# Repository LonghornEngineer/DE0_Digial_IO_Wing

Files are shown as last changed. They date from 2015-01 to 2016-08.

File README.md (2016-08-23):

LHE_BANNER
***
###DE0_Digial_IO_Wing
***
**Digital I/O Expansion Wing for the DE0 FPGA Development Board.**

This is for the [Altera DE0 Development Board by terasIC](http://www.terasic.com.tw/cgi-bin/page/archive.pl?Language=English&No=364). 

See [here for more information](http://longhornengineer.com/category/projects/hardware/de0-digital-io-wing-expansion/).

***
**License Information**

This project is under the [Creative Commons Attribution-ShareAlike 4.0 International License](LICENSE.md). These files are provided with no warranty and should be used at your own risk. 

***

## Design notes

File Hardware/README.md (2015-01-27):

###DE0_Digial_IO_Wing
***
**Digital I/O Expansion Wing for the DE0 FPGA Development Board.**

This is for the [Altera DE0 Development Board by terasIC](http://www.terasic.com.tw/cgi-bin/page/archive.pl?Language=English&No=364). 

Files are for Eagle V6.0+ 

***
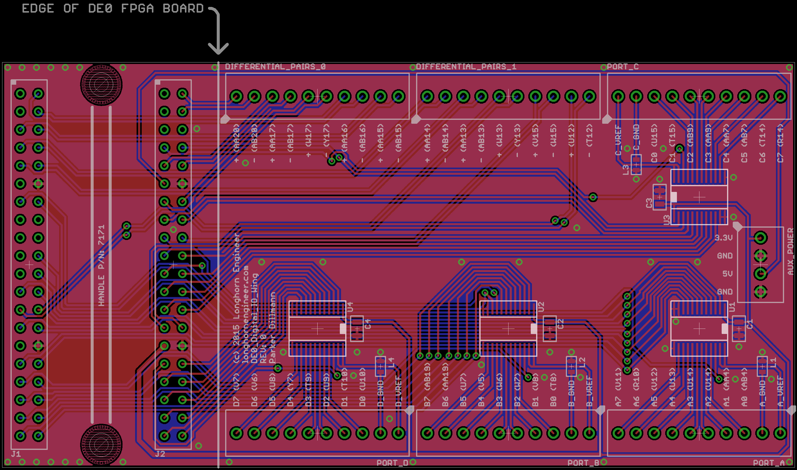
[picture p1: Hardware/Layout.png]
Layout Image


***
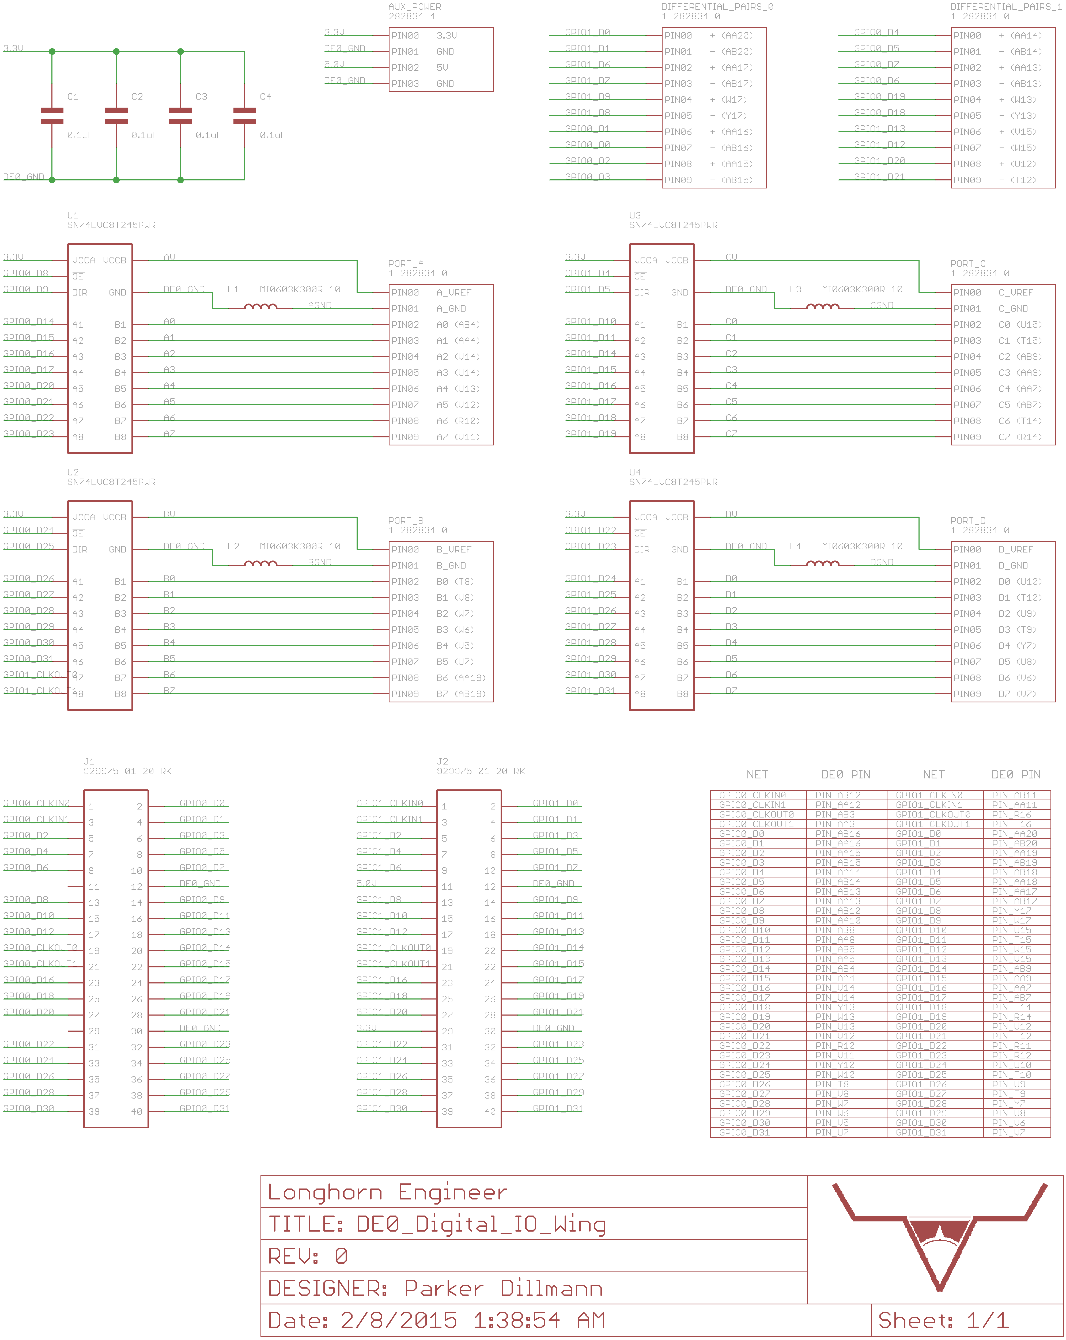
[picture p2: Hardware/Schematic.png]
Schematic Image


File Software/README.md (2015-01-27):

###DE0_Digial_IO_Wing
***
**Digital I/O Expansion Wing for the DE0 FPGA Development Board.**

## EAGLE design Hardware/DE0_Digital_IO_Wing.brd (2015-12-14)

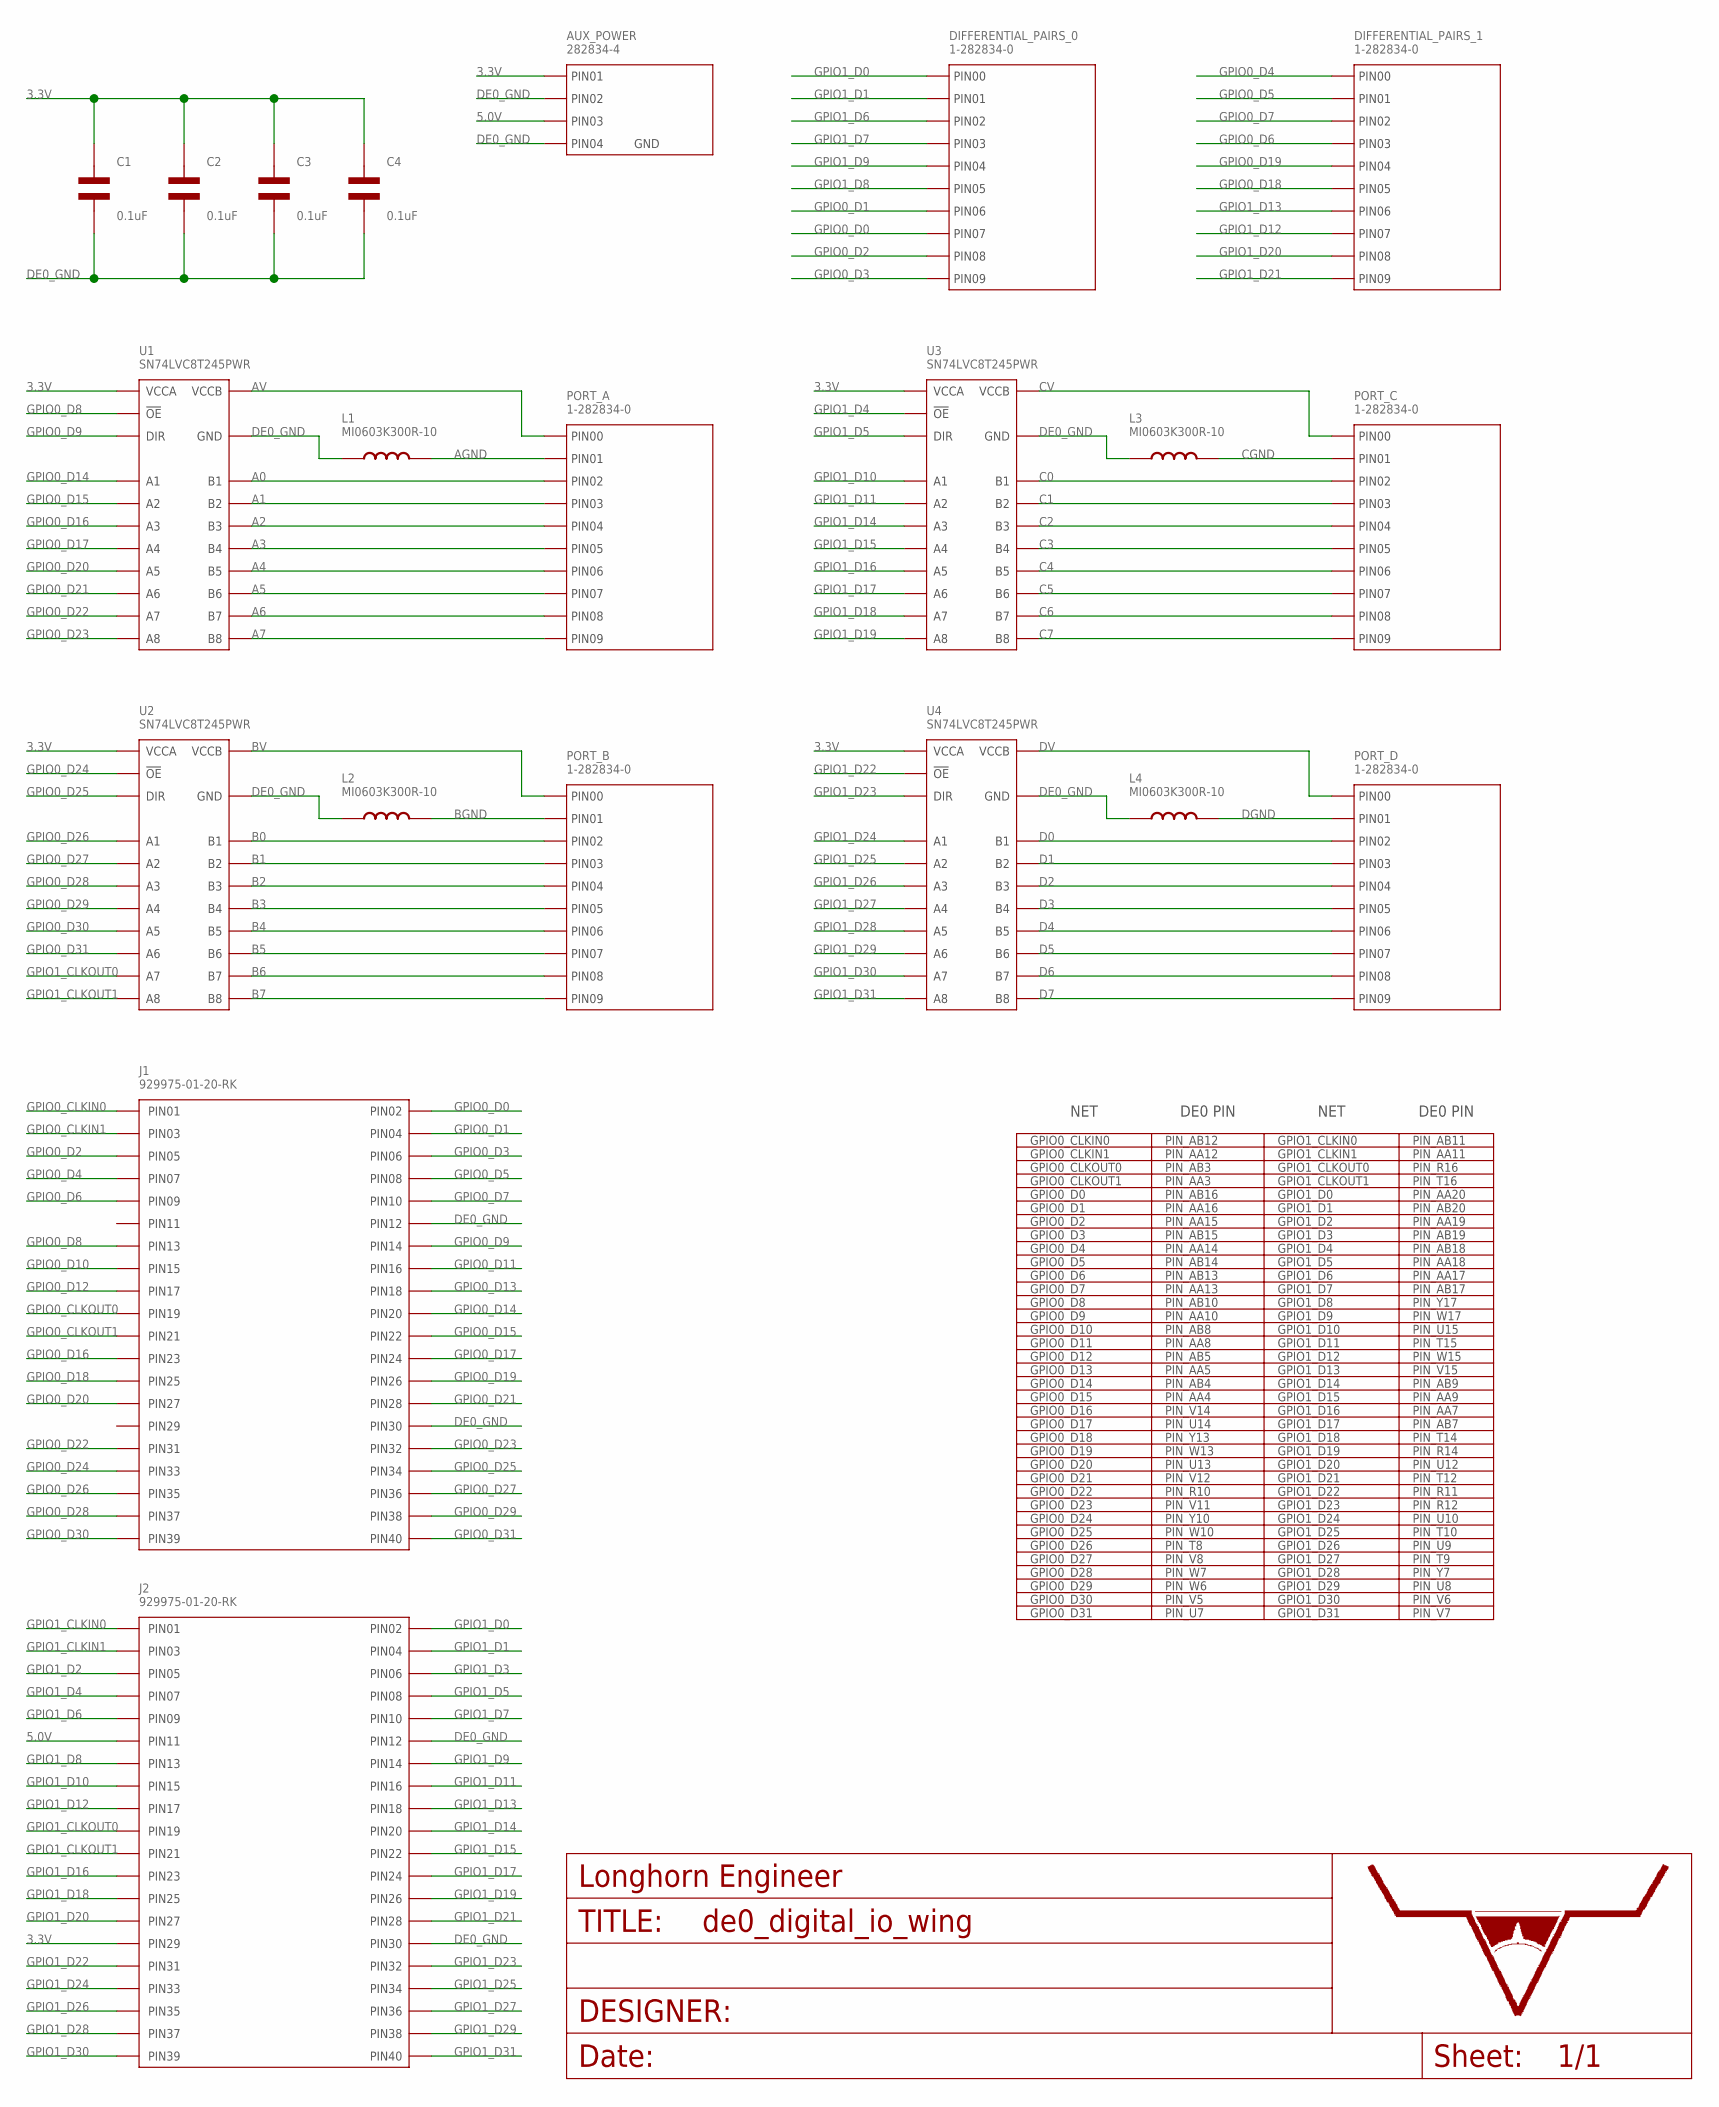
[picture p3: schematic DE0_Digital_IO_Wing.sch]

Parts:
AUX_POWER: 282834-4
C1, C2, C3, C4: 0.1uF; C0805
DIFFERENTIAL_PAIRS_0, DIFFERENTIAL_PAIRS_1: 1-282834-0
FRAME: LHE_FRAME
J1, J2: 929975-01-20-RK; 2.54MM_02X20_PIN_HEADER
L1, L2, L3, L4: MI0603K300R-10; L0603
PORT_A: 1-282834-0
PORT_B: 1-282834-0
PORT_C: 1-282834-0
PORT_D: 1-282834-0
U1, U2, U3, U4: SN74LVC8T245PWR; SN74LVC8T245_TTSOP-24

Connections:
3.3V: AUX_POWER.P$1 (1), C1.P$1, C2.P$1, C3.P$1, C4.P$1, J2.29, U1.P$1 (VCCA), U2.P$1 (VCCA), U3.P$1 (VCCA), U4.P$1 (VCCA)
5.0V: AUX_POWER.P$3 (3), J2.11
A0: PORT_A.P$3 (3), U1.P$21 (B1)
A1: PORT_A.P$4 (4), U1.P$20 (B2)
A2: PORT_A.P$5 (5), U1.P$19 (B3)
A3: PORT_A.P$6 (6), U1.P$18 (B4)
A4: PORT_A.P$7 (7), U1.P$17 (B5)
A5: PORT_A.P$8 (8), U1.P$16 (B6)
A6: PORT_A.P$9 (9), U1.P$15 (B7)
A7: PORT_A.P$10 (10), U1.P$14 (B8)
AGND: L1.P$2, PORT_A.P$2 (2)
AV: PORT_A.P$1 (1), U1.P$23 (VCCB), U1.P$24 (VCCB)
B0: PORT_B.P$3 (3), U2.P$21 (B1)
B1: PORT_B.P$4 (4), U2.P$20 (B2)
B2: PORT_B.P$5 (5), U2.P$19 (B3)
B3: PORT_B.P$6 (6), U2.P$18 (B4)
B4: PORT_B.P$7 (7), U2.P$17 (B5)
B5: PORT_B.P$8 (8), U2.P$16 (B6)
B6: PORT_B.P$9 (9), U2.P$15 (B7)
B7: PORT_B.P$10 (10), U2.P$14 (B8)
BGND: L2.P$2, PORT_B.P$2 (2)
BV: PORT_B.P$1 (1), U2.P$23 (VCCB), U2.P$24 (VCCB)
C0: PORT_C.P$3 (3), U3.P$21 (B1)
C1: PORT_C.P$4 (4), U3.P$20 (B2)
C2: PORT_C.P$5 (5), U3.P$19 (B3)
C3: PORT_C.P$6 (6), U3.P$18 (B4)
C4: PORT_C.P$7 (7), U3.P$17 (B5)
C5: PORT_C.P$8 (8), U3.P$16 (B6)
C6: PORT_C.P$9 (9), U3.P$15 (B7)
C7: PORT_C.P$10 (10), U3.P$14 (B8)
CGND: L3.P$2, PORT_C.P$2 (2)
CV: PORT_C.P$1 (1), U3.P$23 (VCCB), U3.P$24 (VCCB)
D0: PORT_D.P$3 (3), U4.P$21 (B1)
D1: PORT_D.P$4 (4), U4.P$20 (B2)
D2: PORT_D.P$5 (5), U4.P$19 (B3)
D3: PORT_D.P$6 (6), U4.P$18 (B4)
D4: PORT_D.P$7 (7), U4.P$17 (B5)
D5: PORT_D.P$8 (8), U4.P$16 (B6)
D6: PORT_D.P$9 (9), U4.P$15 (B7)
D7: PORT_D.P$10 (10), U4.P$14 (B8)
DE0_GND: AUX_POWER.P$2 (2), AUX_POWER.P$4 (4), C1.P$2, C2.P$2, C3.P$2, C4.P$2, J1.12, J1.30, J2.12, J2.30, L1.P$1, L2.P$1, L3.P$1, L4.P$1, U1.P$11 (GND), U1.P$12 (GND), U1.P$13 (GND), U2.P$11 (GND), U2.P$12 (GND), U2.P$13 (GND), U3.P$11 (GND), U3.P$12 (GND), U3.P$13 (GND), U4.P$11 (GND), U4.P$12 (GND), U4.P$13 (GND)
DGND: L4.P$2, PORT_D.P$2 (2)
DV: PORT_D.P$1 (1), U4.P$23 (VCCB), U4.P$24 (VCCB)
GPIO0_CLKIN0: J1.1
GPIO0_CLKIN1: J1.3
GPIO0_CLKOUT0: J1.19
GPIO0_CLKOUT1: J1.21
GPIO0_D0: DIFFERENTIAL_PAIRS_0.P$8 (8), J1.2
GPIO0_D1: DIFFERENTIAL_PAIRS_0.P$7 (7), J1.4
GPIO0_D2: DIFFERENTIAL_PAIRS_0.P$9 (9), J1.5
GPIO0_D3: DIFFERENTIAL_PAIRS_0.P$10 (10), J1.6
GPIO0_D4: DIFFERENTIAL_PAIRS_1.P$1 (1), J1.7
GPIO0_D5: DIFFERENTIAL_PAIRS_1.P$2 (2), J1.8
GPIO0_D6: DIFFERENTIAL_PAIRS_1.P$4 (4), J1.9
GPIO0_D7: DIFFERENTIAL_PAIRS_1.P$3 (3), J1.10
GPIO0_D8: J1.13, U1.P$22 (!OE)
GPIO0_D9: J1.14, U1.P$2 (DIR)
GPIO0_D10: J1.15
GPIO0_D11: J1.16
GPIO0_D12: J1.17
GPIO0_D13: J1.18
GPIO0_D14: J1.20, U1.P$3 (A1)
GPIO0_D15: J1.22, U1.P$4 (A2)
GPIO0_D16: J1.23, U1.P$5 (A3)
GPIO0_D17: J1.24, U1.P$6 (A4)
GPIO0_D18: DIFFERENTIAL_PAIRS_1.P$6 (6), J1.25
GPIO0_D19: DIFFERENTIAL_PAIRS_1.P$5 (5), J1.26
GPIO0_D20: J1.27, U1.P$7 (A5)
GPIO0_D21: J1.28, U1.P$8 (A6)
GPIO0_D22: J1.31, U1.P$9 (A7)
GPIO0_D23: J1.32, U1.P$10 (A8)
GPIO0_D24: J1.33, U2.P$22 (!OE)
GPIO0_D25: J1.34, U2.P$2 (DIR)
GPIO0_D26: J1.35, U2.P$3 (A1)
GPIO0_D27: J1.36, U2.P$4 (A2)
GPIO0_D28: J1.37, U2.P$5 (A3)
GPIO0_D29: J1.38, U2.P$6 (A4)
GPIO0_D30: J1.39, U2.P$7 (A5)
GPIO0_D31: J1.40, U2.P$8 (A6)
GPIO1_CLKIN0: J2.1
GPIO1_CLKIN1: J2.3
GPIO1_CLKOUT0: J2.19, U2.P$9 (A7)
GPIO1_CLKOUT1: J2.21, U2.P$10 (A8)
GPIO1_D0: DIFFERENTIAL_PAIRS_0.P$1 (1), J2.2
GPIO1_D1: DIFFERENTIAL_PAIRS_0.P$2 (2), J2.4
GPIO1_D2: J2.5
GPIO1_D3: J2.6
GPIO1_D4: J2.7, U3.P$22 (!OE)
GPIO1_D5: J2.8, U3.P$2 (DIR)
GPIO1_D6: DIFFERENTIAL_PAIRS_0.P$3 (3), J2.9
GPIO1_D7: DIFFERENTIAL_PAIRS_0.P$4 (4), J2.10
GPIO1_D8: DIFFERENTIAL_PAIRS_0.P$6 (6), J2.13
GPIO1_D9: DIFFERENTIAL_PAIRS_0.P$5 (5), J2.14
GPIO1_D10: J2.15, U3.P$3 (A1)
GPIO1_D11: J2.16, U3.P$4 (A2)
GPIO1_D12: DIFFERENTIAL_PAIRS_1.P$8 (8), J2.17
GPIO1_D13: DIFFERENTIAL_PAIRS_1.P$7 (7), J2.18
GPIO1_D14: J2.20, U3.P$5 (A3)
GPIO1_D15: J2.22, U3.P$6 (A4)
GPIO1_D16: J2.23, U3.P$7 (A5)
GPIO1_D17: J2.24, U3.P$8 (A6)
GPIO1_D18: J2.25, U3.P$9 (A7)
GPIO1_D19: J2.26, U3.P$10 (A8)
GPIO1_D20: DIFFERENTIAL_PAIRS_1.P$9 (9), J2.27
GPIO1_D21: DIFFERENTIAL_PAIRS_1.P$10 (10), J2.28
GPIO1_D22: J2.31, U4.P$22 (!OE)
GPIO1_D23: J2.32, U4.P$2 (DIR)
GPIO1_D24: J2.33, U4.P$3 (A1)
GPIO1_D25: J2.34, U4.P$4 (A2)
GPIO1_D26: J2.35, U4.P$5 (A3)
GPIO1_D27: J2.36, U4.P$6 (A4)
GPIO1_D28: J2.37, U4.P$7 (A5)
GPIO1_D29: J2.38, U4.P$8 (A6)
GPIO1_D30: J2.39, U4.P$9 (A7)
GPIO1_D31: J2.40, U4.P$10 (A8)

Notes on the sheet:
GPIO0_CLKIN0 GPIO0_CLKIN1 GPIO0_CLKOUT0 GPIO0_CLKOUT1 GPIO0_D0 GPIO0_D1 GPIO0_D2 GPIO0_D3 GPIO0_D4 GPIO0_D5 GPIO0_D6 GPIO0_D7 GPIO0_D8 GPIO0_D9 GPIO0_D10 GPIO0_D11 GPIO0_D12 GPIO0_D13 GPIO0_D14 GPIO0_D15 GPIO0_D16 GPIO0_D17 GPIO0_D18 GPIO0_D19 GPIO0_D20 GPIO0_D21 GPIO0_D22 GPIO0_D23 GPIO0_D24 GPIO0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
GPIO1_CLKIN0 GPIO1_CLKIN1 GPIO1_CLKOUT0 GPIO1_CLKOUT1 GPIO1_D0 GPIO1_D1 GPIO1_D2 GPIO1_D3 GPIO1_D4 GPIO1_D5 GPIO1_D6 GPIO1_D7 GPIO1_D8 GPIO1_D9 GPIO1_D10 GPIO1_D11 GPIO1_D12 GPIO1_D13 GPIO1_D14 GPIO1_D15 GPIO1_D16 GPIO1_D17 GPIO1_D18 GPIO1_D19 GPIO1_D20 GPIO1_D21 GPIO1_D22 GPIO1_D23 GPIO1_D24 GPIO1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
PIN_AB12 PIN_AA12 PIN_AB3 PIN_AA3 PIN_AB16 PIN_AA16 PIN_AA15 PIN_AB15 PIN_AA14 PIN_AB14 PIN_AB13 PIN_AA13 PIN_AB10 PIN_AA10 PIN_AB8 PIN_AA8 PIN_AB5 PIN_AA5 PIN_AB4 PIN_AA4 PIN_V14 PIN_U14 PIN_Y13 PIN_W13 PIN_U13 PIN_V12 PIN_R10 PIN_V11 PIN_Y10 PIN_W10 PIN_T8 PIN_V8 PIN_W7 PIN_W6 PIN_V5 PIN_U7
PIN_AB11 PIN_AA11 PIN_R16 PIN_T16 PIN_AA20 PIN_AB20 PIN_AA19 PIN_AB19 PIN_AB18 PIN_AA18 PIN_AA17 PIN_AB17 PIN_Y17 PIN_W17 PIN_U15 PIN_T15 PIN_W15 PIN_V15 PIN_AB9 PIN_AA9 PIN_AA7 PIN_AB7 PIN_T14 PIN_R14 PIN_U12 PIN_T12 PIN_R11 PIN_R12 PIN_U10 PIN_T10 PIN_U9 PIN_T9 PIN_Y7 PIN_U8 PIN_V6 PIN_V7
NET
DE0 PIN

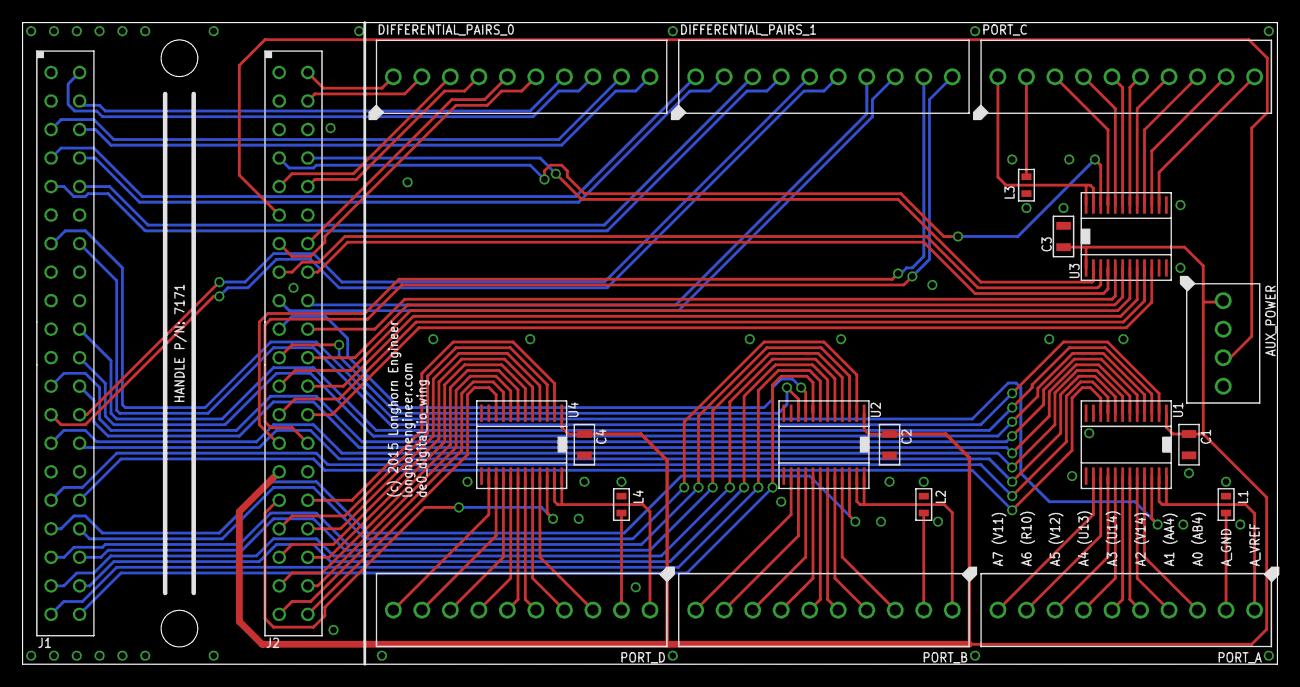
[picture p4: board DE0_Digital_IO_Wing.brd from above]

Board: 2 copper layers, 111.8 x 57.1 mm, 22 parts (0 on the bottom side), 103 nets.

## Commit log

2015-01-27 First Commit. Adding Eagle files and Readme/License
    [DE0_Digital_IO_Wing.brd, DE0_Digital_IO_Wing.sch]
2015-02-02 Working on layout.
    [DE0_Digital_IO_Wing.brd, DE0_Digital_IO_Wing.sch]
2015-02-08 REV0 preliminary complete.
    [DE0_Digital_IO_Wing.brd, DE0_Digital_IO_Wing.sch]
2015-02-08 Fixed some traces crossing gnd planes.
    [DE0_Digital_IO_Wing.brd, DE0_Digital_IO_Wing.sch]
2015-02-08 fixed silkscreen in some places.
    [DE0_Digital_IO_Wing.brd]
2015-02-08 Fixed weird missing trace from Pin3 U1
    [DE0_Digital_IO_Wing.brd, DE0_Digital_IO_Wing.sch]
2015-02-13 fixed silkscreen around ICs
    [DE0_Digital_IO_Wing.brd, DE0_Digital_IO_Wing.sch]
2015-03-03 Adding first push of verilog code.
    Need to do pin planning and testing. Compiles tho. So there is that.
2015-12-14 Bringing it to current library spec.
    [DE0_Digital_IO_Wing.brd, DE0_Digital_IO_Wing.sch]

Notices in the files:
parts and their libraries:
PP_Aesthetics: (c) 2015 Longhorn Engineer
